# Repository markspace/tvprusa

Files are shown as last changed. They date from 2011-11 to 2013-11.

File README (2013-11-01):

TVRRUG Prusa Mendel Round 3

These are the files for the TVRRUG Round 3 version of the Prusa Mendel

Please read http://tvrrug.org.uk/tvprusa before attempting to build this.

Imported stuff:
Frame vertices are based on Viks and Tonokips ones
Extruder by Wade
Parametric Involute Bevel and Spur Gears by GregFrost
Belt pulley is http://www.thingiverse.com/thing:11256 by droftarts
Most of the rest from Josef Prusa

To print:

6x frame-vertex-without-foot or 2x -without-foot and 4x -with-foot
4x coupling
3x endstop-holder
1x x-carriage
1x x-end-idler
1x x-end-motor
2x z-motor-mount
4x belt-clamp
8x bar-clamp
2x rod-clamp
2x 9-tooth-pulley-TVRRUG
1x herringbone-wadebits (11 tooth drive gear and 45 tooth gear)
4x SpringSeat (extruder spring retainer)
1x wade (extruder block)
4x spring
1x y-idler
1x ybrac-t
2x zizolator

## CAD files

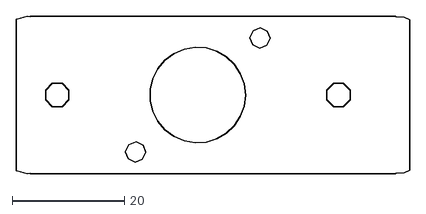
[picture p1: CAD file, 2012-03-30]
DXFs/extruder_mounting_plate.dxf
70.0 x 28.0

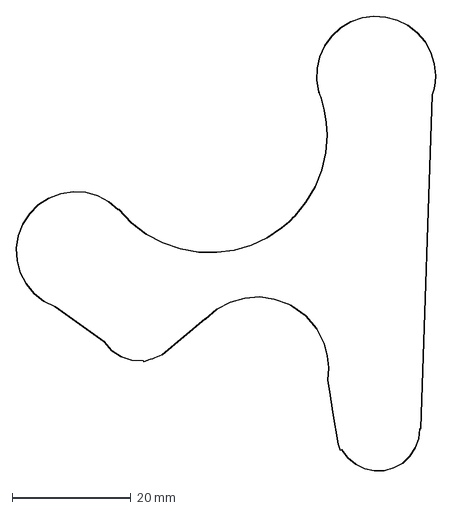
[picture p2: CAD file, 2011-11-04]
SCADs/ybrac-t.dxf
70.5 x 76.4 mm

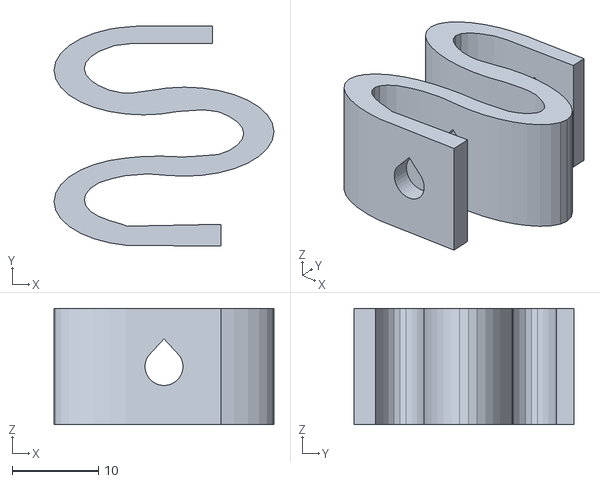
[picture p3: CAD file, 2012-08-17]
STLs/bed-spring_4off.stl
25.5 x 25.5 x 13.5

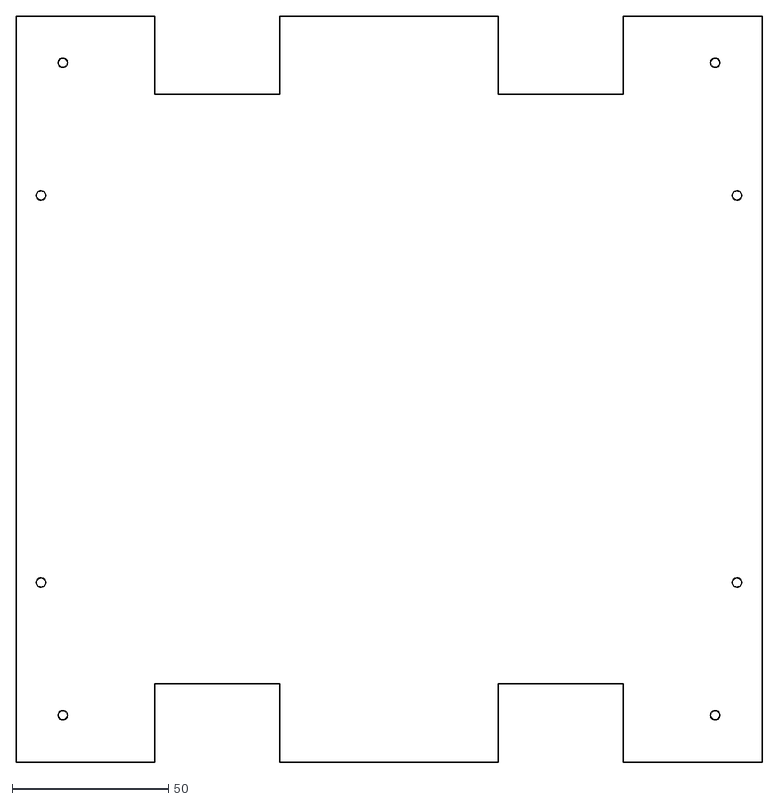
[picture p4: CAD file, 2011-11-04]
DXFs/printtop.dxf
239.0 x 239.0

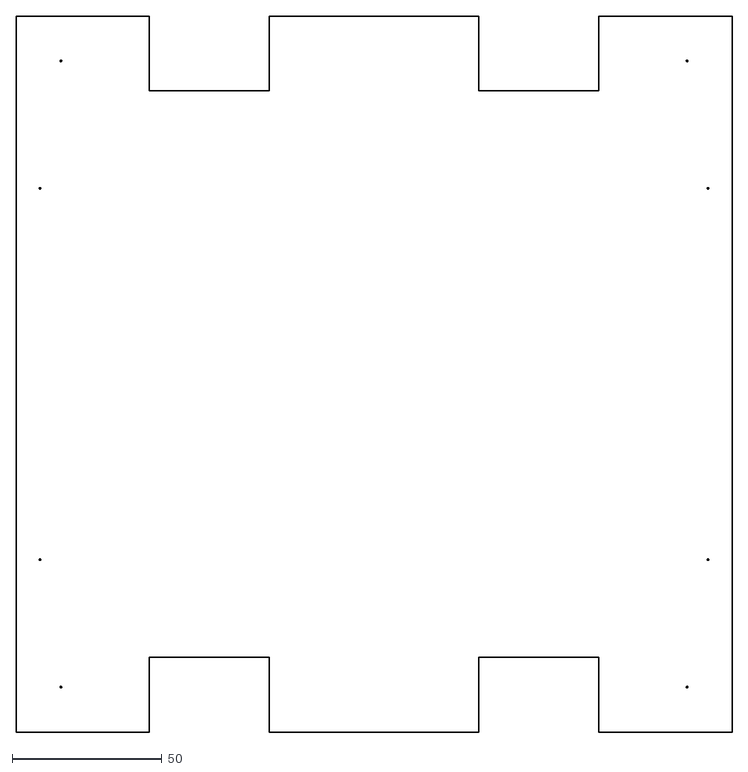
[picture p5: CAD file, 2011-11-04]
DXFs/printtopdots.dxf
239.0 x 239.0

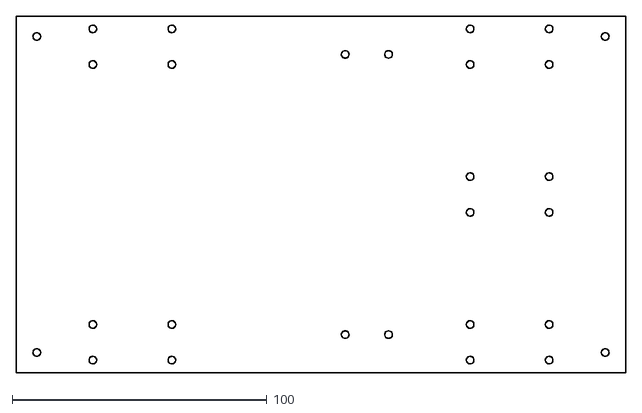
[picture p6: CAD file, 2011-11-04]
DXFs/printbottom.dxf
239.0 x 140.0

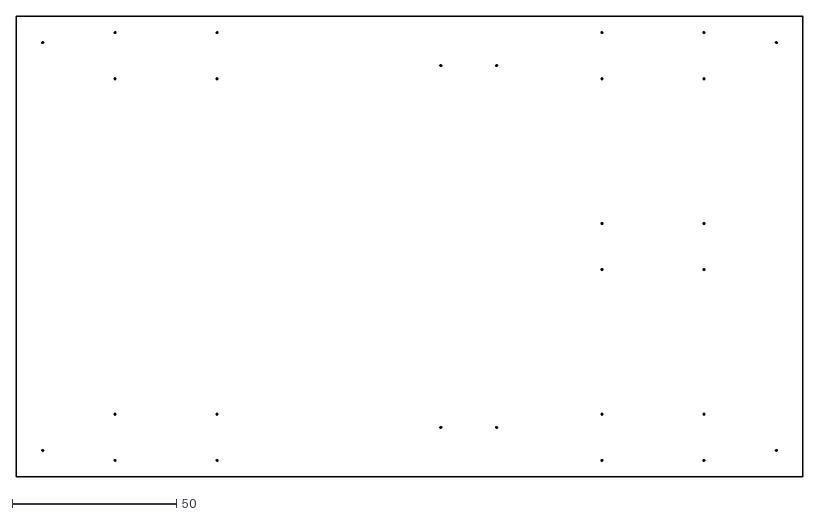
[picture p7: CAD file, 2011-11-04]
DXFs/printbottomdots.dxf
239.0 x 140.0

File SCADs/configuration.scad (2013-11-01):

// PRUSA Mendel  
// Configuration file
// GNU GPL v2
// Josef Průša
// josefprusa@me.com
// prusadjs.cz
// http://www.reprap.org/wiki/Prusa_Mendel
// http://github.com/prusajr/PrusaMendel

include <metric.scad>;

// CUSTOM CUSTOM CUSTOM CUSTOM CUSTOM CUSTOM CUSTOM CUSTOM CUSTOM

// Thin walls
layer_height = 0.3;
wot = 1.5;
filament_width = layer_height * wot;

thin_wall = 4 * layer_height * wot;

// LM8UU
linear = true;
linear_bearing_diameter = 15;
linear_bearing_length = 24;

//608 bearing
bearing_diameter = 22;
bearing_thickness = 7;

//Timing belt
belt_pitch = 5;

// CHANGE ONLY THE STUFF YOU KNOW
// IT WILL REPLACE DEFAULT SETTING

// RODS

// threaded_rod_diameter = 0;
// threaded_rod_diameter_horizontal = 0;
// smooth_bar_díameter = 0;
// smooth_bar_díameter_horizontal = 0;

// Nuts and bolts

// m8_diameter = 0;
// m8_nut_diameter = 0;
// m8_nut_thickness = 0;

// m4_diameter = 0;
 m4_nut_diameter = 8.5;
// m4_nut_thickness = 0;

// m3_diameter = 0;
// m3_nut_diameter = 0;
m3_nut_thickness = 3;

// Bushing holder

// bushing_core_diameter = smooth_bar_díameter;
// bushing_material_thickness = 0;

///counted stuff
m3_nut_diameter_bigger = ( ( m3_nut_diameter  / 2) / cos( 180 / 6 ) ) * 2;

// functions 
include <functions.scad>

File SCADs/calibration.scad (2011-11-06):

// PRUSA Mendel  
// Configuration test
// GNU GPL v2
// Josef Průša
// josefprusa@me.com
// prusadjs.cz
// http://www.reprap.org/wiki/Prusa_Mendel
// http://github.com/prusajr/PrusaMendel

include <configuration.scad>

/**
 * @id calibration
 * @name Configuration test
 */

configurationtest();

module configurationtest()
{
	difference()
	{
		union()
		{
			rotate( a = [0, 0, 30] ) cylinder( h = 10, r = ( m8_nut_diameter / 2 ) + 4, $fn = 6 );
			translate( v = [( ( ( m8_diameter / 2 ) + 3 ) * 2 + ( m3_diameter / 2 ) + 2 + ( ( ( m3_diameter / 2 ) + 2 ) * 2 ) / 2 ) / 2, 0,5] ) cube( size = [( ( m8_diameter / 2 ) + 3 ) * 2 + ( m3_diameter / 2 ) + 2 + ( ( ( m3_diameter / 2 ) + 2 ) * 2 ) / 2, ( ( m8_nut_diameter / 2 ) + 4 ) * 2, 10], center = true );

			translate( v = [( ( m8_diameter / 2 ) + 3 ), ( m8_nut_diameter / 2 ) + 2, ( ( m8_diameter ) + 15 ) / 2]) cube( size = [( ( m8_diameter / 2 ) + 3 ) * 2, 4, ( m8_diameter ) + 15], center = true );
			//translate( v = [( m8_diameter / 2 ) + 3, ( m8_nut_diameter / 2 ) + 4, ( m8_diameter / 2 ) + 10] ) rotate( a = [90, 0, 0] ) cylinder( h = 4, r = ( m8_diameter / 2 ) + 3 );

			translate( v = [( ( m8_diameter / 2 ) + 3 ) * 2 + ( m3_diameter / 2 ) + 1.9, ( m8_nut_diameter / 2 ) + 2, ( ( m8_diameter ) + 15 ) / 2] ) cube( size = [( ( m3_diameter / 2 ) + 2.1 ) * 2, 4, ( m8_diameter ) + 15], center = true);
			//translate( v = [( ( m8_diameter / 2 ) + 3 ) * 2 + ( m3_diameter / 2 ) + 2, ( m8_nut_diameter / 2 ) + 4, ( m8_diameter / 2 ) + 10] ) rotate( a = [90, 0, 0] ) cylinder( h = 4, r = ( m3_diameter / 2 ) + 2 );
		}
		translate( v = [( m8_diameter / 2 ) + 3, ( m8_nut_diameter / 2 ) + 5, ( m8_diameter / 2 ) + 10] ) rotate( a = [90, 0, 0] ) cylinder( h = 6, r = ( m8_diameter / 2 ) );
		translate( v = [( ( m8_diameter / 2 ) + 3 ) * 2 + ( m3_diameter / 2 ) + 2, ( m8_nut_diameter / 2 ) + 5, ( m8_diameter / 2 ) + 10] ) rotate( a = [90, 0, 0] ) cylinder( h = 6, r = ( m3_diameter / 2 ) );
		translate( v = [0, 0, -1] ) cylinder( h = 15, r = ( m8_diameter / 2 ) );
		translate( v = [( m8_nut_diameter / 2 ) + ( m3_nut_diameter / 2 ) + 2, 0, -1] ) cylinder( h = 15, r = ( m3_diameter / 2 ) );
		translate( v = [( m8_nut_diameter / 2 ) + ( m3_nut_diameter / 2 ) + 2, 0, 5] ) rotate( a = [0, 0, 30] ) cylinder( h = 15, r = ( m3_nut_diameter / 2 ), $fn = 6 );
		rotate( a = [0, 0, 30] ) translate( v = [0, 0, 5] ) cylinder( h = 15, r = ( m8_nut_diameter / 2 ), $fn = 6 );

		translate( v = [( ( m8_diameter / 2 ) + 3 ) * 2 + ( m3_diameter / 2 ) + 2 + ( ( ( m3_diameter / 2 ) + 2 ) * 2 ) / 2 - 4, 0, 0] ) rotate( a = [0, 0, -25] ) difference()
		{
		 	translate( v = [0, 0, -1] ) cube(size = [10, 10, 20] );
		 	rotate( a = [0, 0, 50] ) translate( v = [0, 0, -1.5] ) cube( size = [30, 30, 21] );
		}
	
		translate( v = [( ( m8_diameter / 2 ) + 3 ) * 2 + ( m3_diameter / 2 ) + 2 + ( ( ( m3_diameter / 2 ) + 2 ) * 2 ) / 2 - 4, -3.7, 0] ) rotate( a = [0, 0, -25] ) difference()
		{
	 		translate( v = [0, 0, -1] ) cube( size = [10, 10, 20] );
		 	rotate( a = [0, 0, 50] ) translate( v = [0, 0, -1.5] ) cube( size = [30, 30, 21] );
		}
	
		translate( v = [( ( m8_diameter / 2 ) + 3 ) * 2 + ( m3_diameter / 2 ) + 2 + ( ( ( m3_diameter / 2 ) + 2 ) * 2 ) / 2 - 4, 3.7, 0] ) rotate( a = [0, 0, -25] ) difference()
		{
		 	translate( v = [0, 0, -1] ) cube( size = [10, 10, 20] );
		 	rotate( a = [0, 0, 50] ) translate( v = [0, 0, -1.5] ) cube( size = [30, 30, 21] );
		}
	}
}

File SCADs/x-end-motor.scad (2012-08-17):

// PRUSA Mendel  
// X-end with NEMA 17 motor mount
// GNU GPL v3
// Josef Průša
// josefprusa@me.com
// prusadjs.cz
// http://www.reprap.org/wiki/Prusa_Mendel
// http://github.com/prusajr/PrusaMendel

include <configuration.scad>
use <teardrop.scad>
correction = 1.17; 

z_rod_leadscrew_spacing=31.5;
z_alignment_fix=z_rod_leadscrew_spacing-29.5;

x_belt_center_offset=39.5;
belt_width=5;
motor_center_depth=2;
motor_face_belt_center_offset=belt_width/2+motor_center_depth+2;
x_belt_alignment_fix = x_belt_center_offset-(44-motor_face_belt_center_offset);

/**
 * @id x-end-motor
 * @name X end motor
 * @category Printed
 * @using 2 bushing
 * @using 4 m3x10xhex
 * @using 4 m3washer
 * @using 1 m8spring
 * @using 2 m8nut
 */

use <x-end.scad>

xendmotor(curved_sides=true,closed_end=true,linear_bearing=true);

module xendmotor(curved_sides=false,closed_end=true,linear_bearing=false)
{
	difference ()
	{
		union ()
		{
			xend(closed_end=closed_end,
				curved_sides=curved_sides,
				linear_bearing=linear_bearing);
//			import_stl("x-end.stl");
		
			positioned_motor_mount();
		}
		positioned_motor_mount_holes();
		xendcorners(5,0,5,5,0);
	}
}

// GregFrosts stuff
nema17_hole_spacing=1.2*25.4; 
nema17_width=1.7*25.4;
thickness=9;
nema17_support_d=nema17_width-nema17_hole_spacing;
motor_mount_rotation=[0,0,0];
motor_mount_translation=[44-thickness+x_belt_alignment_fix,8+z_alignment_fix,23.5-4.7-12+24.5];

top_corner=motor_mount_translation+[thickness,nema17_width/2,nema17_width/2];
bridge_length=top_corner[0]-9;
//bridge_shear=0.48;
bridge_shear=(top_corner[1]-nema17_support_d-z_alignment_fix)/bridge_length;

module positioned_motor_mount()
{
	difference ()
	{
		translate(motor_mount_translation)
		union()
		{
			rotate([0,90,0])
			motor_mount ();
			
			translate(-motor_mount_translation)
			{
				translate(top_corner+
				[-bridge_length,-nema17_support_d-bridge_shear*bridge_length,-2.5])
				multmatrix([[1,0,0],[bridge_shear,1,0],[0,0,1]])
				cube([bridge_length,nema17_support_d,6]);
				
				render()
				translate(top_corner+[-thickness,-nema17_support_d,-nema17_support_d/2])
				intersection()
				{
					translate([0,-bridge_shear*thickness,0])
					multmatrix([[1,0,0],[bridge_shear,1,0],[0,0,1]])
					cube([thickness,nema17_support_d,nema17_support_d/2]);
					cube([thickness,nema17_support_d,nema17_support_d/2]);
				}
			}
			
			translate([-x_belt_alignment_fix/2,0,0])
			scale([1+x_belt_alignment_fix/(thickness*2),1,1])
			render()
			intersection()
			{
				translate([0,-nema17_width/2+nema17_support_d/2,1])
				rotate([0,90,0])
				translate([3.6*1.5*thickness,0,-thickness])
				multmatrix([[1,0,-3.6],[0,1,0],[0,0,2]])
				{
					rotate(90)
					linear_extrude(height=thickness)
					barbell(nema17_support_d/2,
					nema17_support_d/2,20,60,nema17_hole_spacing);
					translate([-20,-nema17_support_d/2,0])
					cube([20,nema17_width,thickness]);
				}
				
				translate([0,0,-motor_mount_translation[2]+15.8/2])
				cube([thickness*3,nema17_width,15.8],true);
			}
		}

		translate([25,-26,15.8/2])
		rotate(90) 
		teardropcentering(6,42);

		translate(motor_mount_translation)
		translate([-26.25-x_belt_alignment_fix,-nema17_width/2-1-16,-32])
		cube([20,nema17_width+2,20]);
	}
}

module positioned_motor_mount_holes()
{
	translate(motor_mount_translation)
	rotate([0,90,0])
	motor_mount_holes ();
}

module motor_mount ()
{
	rotate(motor_mount_rotation)
	{
		for (hole=[1,2])
		rotate([0,0,90*hole])
		linear_extrude(height=thickness)
		translate(-nema17_hole_spacing*[1,1,0]/2)
		barbell (nema17_support_d/2,
		nema17_support_d/2,20,60,nema17_hole_spacing);
		% cube([nema17_width,nema17_width,0.1],true);
	}
}

module motor_mount_holes ()
{
	// Motor mount holes. 
	translate([0,0,1])
	rotate(motor_mount_rotation)
	{
		for (hole=[3:5])
		rotate([0,0,90*hole])
		translate(nema17_hole_spacing*[1,1,0]/2)
		rotate(360/16)
		cylinder(h=thickness+2,r=4.4/2,$fn=8);
		
		for (hole=[3:5])
		rotate([0,0,90*hole])
		translate(nema17_hole_spacing*[1,1,0]/2)
		translate([0,0,-24-x_belt_alignment_fix])
		cylinder(h=25+x_belt_alignment_fix,r=7/2);
	}
	
	translate([-7/2-0.5-(nema17_width/2-nema17_hole_spacing/2),0,0])
	rotate(270)
	translate([0,0,-1])
	cube([nema17_width/2,nema17_width/2,thickness+2]);

}

module barbell (r1,r2,r3,r4,separation) 
{
	x1=[0,0];
	x2=[separation,0];
	x3=triangulate (x1,x2,r1+r3,r2+r3);
	x4=triangulate (x2,x1,r2+r4,r1+r4);
	render()
	difference ()
	{
		union()
		{
			translate(x1)
			circle (r=r1);
			translate(x2)
			circle(r=r2);
			polygon (points=[x1,x3,x2,x4]);
		}
		translate(x3)
		circle(r=r3,$fa=5);
		translate(x4)
		circle(r=r4,$fa=5);
	}
}

function triangulate (point1, point2, length1, length2) = 
point1 + 
length1*rotated(
atan2(point2[1]-point1[1],point2[0]-point1[0])+
angle(distance(point1,point2),length1,length2));

function distance(point1,point2)=
sqrt((point1[0]-point2[0])*(point1[0]-point2[0])+
(point1[1]-point2[1])*(point1[1]-point2[1]));

function angle(a,b,c) = acos((a*a+b*b-c*c)/(2*a*b)); 

function rotated(a)=[cos(a),sin(a),0];

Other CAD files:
SCADs/inc/parametric_involute_gear_v5.0.scad
SCADs/9-tooth-pulley-TVRRUG.scad
SCADs/SpringSeat.scad
SCADs/bar-clamp.scad
SCADs/belt-clamp.scad
SCADs/bushing.scad
SCADs/coupling.scad
SCADs/endstop-holder.scad
SCADs/functions.scad
SCADs/herringbone-wadebits.scad
SCADs/inc/teardrop.scad
SCADs/metric.scad
SCADs/rod-clamp.scad
SCADs/spring.scad
SCADs/teardrop.scad
SCADs/thicksheet.scad
SCADs/vertex.scad
SCADs/wade.scad
SCADs/x-carriage.scad
SCADs/x-end-idler.scad
SCADs/x-end.scad
SCADs/x-lm8uu-holder.scad
SCADs/y-idler.scad
SCADs/ybrac-t.scad
SCADs/z-motor-mount.scad
SCADs/zizolator.scad

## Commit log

2011-11-03 Import Prusa felt branch
    Imported felt branch from Prusa (needed for LM8UU) - SCAD files, thingdoc and STL generation scripts
    [bar-clamp.stl, bar-clamps.stl, bearing-guide.stl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]
2011-11-04 Rename source folder to SCADs
    Moving to agreed structure for TVRRUG repo: SCADs, DXFs, STLs.
    [bar-clamp.scad, bearing-guide.scad, belt-clamp-bed-holder.scad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]
2011-11-04 Add DXFs for thick sheet parts
    Generated by thicksheet.scad. In case we want to get thick sheet parts laser cut. Also can be printed out as templates for cutting by hand.
    [printbottom.dxf, printbottomdots.dxf, printtop.dxf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]
2011-11-04 Add nut thickness values and set config values in configuration.scad.
    Nut thickness values will be useful for trapped nuts.
    [configuration.scad]
2011-11-04 Set linear to true.
    We are using LM8UU bearings.
    [configuration.scad]
2011-11-04 Use configuration values in bearing-guide.scad. Add lip and tolerance.
    Move as many values as possible to configuration.scad to make configuration easier. Can be a tight fit between inner and outer parts so added a tolerance.
    [bearing-guide.scad, configuration.scad]
2011-11-04 Use configuration values in coupling.scad. Update shaft diameter.
    Configuration values in one place as much as possible makes everything easier. OD of tube we are using is 8mm.
    [coupling.scad]
2011-11-04 Fix configuration.scad compilation error.
    Missing t; now replaced!
    [configuration.scad]
2011-11-05 Parameterise belt-clamp.scad and adjust for belt pitch.
    We need flexibility to use T5 timing belt, original was T2.5. Added belt_pitch variable to configuration.scad
    [belt-clamp.scad, configuration.scad]
2011-11-05 Remove belt-clamp-bed-holder.scad.
    Don't need this - X belt clamps will be in x carriage file, Y belt clamps are from belt-clamp.scad
    [belt-clamp-bed-holder.scad]
2011-11-05 Correct length spelling mistakes.
    [bushing.scad]
2011-11-06 Shorten x end linear bearing holder and begin parameterisation.
    Moved linear bearing dimensions to configuration.scad as these are used in several parts. Shorten x ends to by removing gap between bearings to improve strength.
    [bushing.scad, configuration.scad]
2011-11-06 Make indentation and layout consistent, add variable names to function calls.
    For ease of reading.
    [x-end.scad]
2011-11-06 Take linear bearing value from configuratin in xend module call.
    When file is rendered, object now reflects bushing type.
    [x-end.scad]
2011-11-06 Replace Prusa X ends with Greg Frost's.
    Provides options for endstop mounts and variable X smooth rod lengths.
    [bushing.scad, x-end-idler.scad, x-end-motor.scad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]
2011-11-06 Delete printable-bushing.scad
    Legacy file, unnecessary since we are using linear bearings, and requiring parameters in configuration.scad that have been removed.
    [printable-bushing.scad]
2011-11-06 Adjustments to bearing diameter.
    Moved the tolerance into bearing-guide.scad so the bearing_diameter value can be used in other parts.
    [bearing-guide.scad, configuration.scad, frame-vertex.scad]
2011-11-06 Add JHead nozzle option.
    We are using JHead nozzles which need a deep recess.
    [wade.scad]
2011-11-06 Extend idler height.
    Provides more leverage against extruder springs, enabling filament to be removed easily.
    [wade.scad]
2011-11-06 Remove y-bushing.scad
    We are not using printed bushings.
    [y-bushing.scad]
2011-11-06 Formatting changes.
    Make layout consistent and code easier to read.
    [bar-clamp.scad, bearing-guide.scad, bushing.scad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]
2011-11-06 Add bed springs STL file
    Do not have SCAD source file for this yet.
    [bed-spring_4off.stl]
2011-11-06 Add spring seats SCAD source file
    For keeping the extruder springs straight and exerting even pressure
    [SpringSeat.scad]
2011-11-06 Use configuration file for variables
    Take diameter of centre hole from configuration.scad for consistency and ease of maintenance.
    [SpringSeat.scad]
2011-11-06 Add Y axis LM8UU holders SCAD file
    Used to mount the print bottom thick sheet part on the Y axis smooth rods using LM8UU linear bearings.
    [lm8uu-holder.scad]
2011-11-06 Add Greg Frost X carriage.
    Renaming lm8uu-holder to y-lm8uu-holder for clarity.
    [gregs-lm8uu-holder.scad, gregs-x-carriage.scad, y-lm8uu-holder.scad]
2011-11-06 Replace x-carriage with GregFrost version.
    Rename gregs-lm8uu-holder to x-lm8uu-holder for clarity.
    [gregs-x-carriage.scad, x-carriage.scad, x-lm8uu-holder.scad]
2011-11-06 Z Motor Mount with TVRRUG logo.
    Helping keep track of the lineage.
    [TVRR.dxf]
2011-11-07 Include configuration.scad
    Fixed missing variables problem.
    [bearing-guide.scad]
2011-11-07 Perfected the tolerances.
    So they don't break as often when putting them together.
    [bearing-guide.scad]
2011-11-09 Correct error in code - shaft grooves both using threaded rod diameter.
    Now coupling can accommodate different sizes of motor shaft.
    [coupling.scad]
2011-11-09 Make X ends for LM8UU bearings not LM8L
    [x-end-idler.scad, x-end-motor.scad]
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2011-11-09 Replace with Ian's version.
    Produces cleaner STLs and has slimmed down the plate where it joins the bottom sheet as it was over-engineered.
    [y-lm8uu-holder.scad]
2011-11-09 Use configuration variables for M3 nut and bolt diameters.
    Ease of maintainability.
    [y-lm8uu-holder.scad]
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2011-12-06 Fix belt clamp hole spacing to match belt clamp.
    [printbottom.dxf, printbottomdots.dxf, thicksheet.scad]
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2012-03-23 Delete superfluous thicksheet DXF files.
    Milling these on CNC so don't need template for drilling by hand.
    [printbottomdots.dxf, printtopdots.dxf]
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2012-03-23 Wade corner rounding fix.
    One corner was missed.
    [wade.scad]
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2012-03-27 Correct Z motor mounts for misalignment with X ends.
    Fixes wonky leadscrews.
    [rod-clamp.scad, z-motor-mount.scad]
2012-03-30 DXF template for plywood extruder mounting plate.
    Adds height and provides extra thermal barrier for extruder body.
    [extruder_mounting_plate.dxf]
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2012-03-30 Add new calibration objects for testing nut and bolt size parameters.
    Verify parameters when printing both horizontally and vertically.
    [calibration.scad]
2012-03-30 Add function to calculate nut corner diameter from nut flat diameter.
    Calibration parameters specify nut flat diameter. It is useful to know nut corner diameter for modelling nut traps etc.
    [functions.scad]
2012-03-30 Fix code formatting.
    Making it nice and neat.
    [vertex.scad]
2012-03-30 Reduce JHead recess depth to 10mm.
    It was too deep at 16mm.
    [wade.scad]
2012-03-30 Remove references to missing NEMA17.scad library.
    [z-motor-mount.scad]
2012-04-02 Endstop holder for 6.5mm microswitch.
    Redesign for small microswitch.
    [bearing-guide.scad, bushing.scad, endstop-holder-6.5mm-microswitch.scad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]
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2012-08-17 Fix herringbone wadebits; remove extra files.
    Updated parametric_involute_gear to fix herringbone wadebits. Removed extraneous endstop holder and lm8uu holder files.
    [endstop-holder-6.5mm-microswitch.scad, parametric_involute_gear_v5.0.scad, y-lm8uu-holder.scad]
2012-08-17 Symmetrical coupling.
    Make the Z leadscrew coupling symmetrical wrt nut traps to reduce number of distinct parts.
    [coupling.scad]
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2012-08-23 Spring stiffness.
    Change spring wall thickness to give printed spring sufficient stiffness for use as bed springs.
    [spring.scad]
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2012-09-06 Remove teardrop holes for tighter fit of threaded rod.
    [vertex.scad]
2012-09-06 Reduce hot end recess depth and remove hot end mounting bolt holes; elongate idler mounting holes.
    Recess for hot end can be reduced in depth and mounting bolt holes removed due to move from washer mounting system to notch + plate mounting.
    Idler mounting holes elongated for more freedom of movement about hinge.
    [wade.scad]
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2012-09-27 Chamfer idler support to fit m3 nut.
    Moving idler support to align belt on centre of double bearing means it interferes with the bolt head or nut. Adding the chamfer allows room for a nut.
    [x-end-idler.scad]
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2013-11-01 m8 -> threaded rod size for vertex holes - from hannah's repo
    [vertex.scad]
